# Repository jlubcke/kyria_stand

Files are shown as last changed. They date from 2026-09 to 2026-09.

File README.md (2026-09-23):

# Kyria tenting stand

Tenting stand for a splitkb Kyria rev3 half, modelled in OpenSCAD from the
official bottom-plate DXF. Two parts in one print:

- A **collar** in the keyboard's own frame: a wall perpendicular to the bottom
  plate, following the case outline, with a small inward ledge the plate rests
  on and a sloped underside below it. It tilts with the keyboard, so the case
  fits exactly at every height of the lip.
- A **pedestal** below it with vertical walls straight down to the desk. Its
  outer face is set in 1 mm so the collar overhangs it as a design line. The
  pedestal carries the optional honeycomb cut-out.

No floor, no bottom. Prints upright with no supports.

| `pattern = "none"` | `pattern = "hex"` | `pattern = "voronoi"` |
| :---: | :---: | :---: |
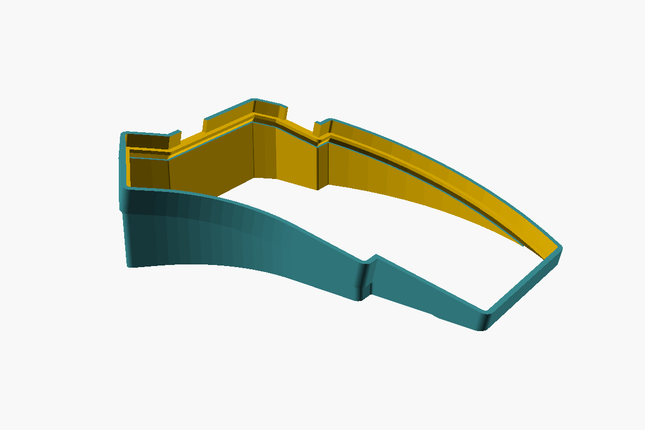
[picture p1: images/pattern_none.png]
plain walls
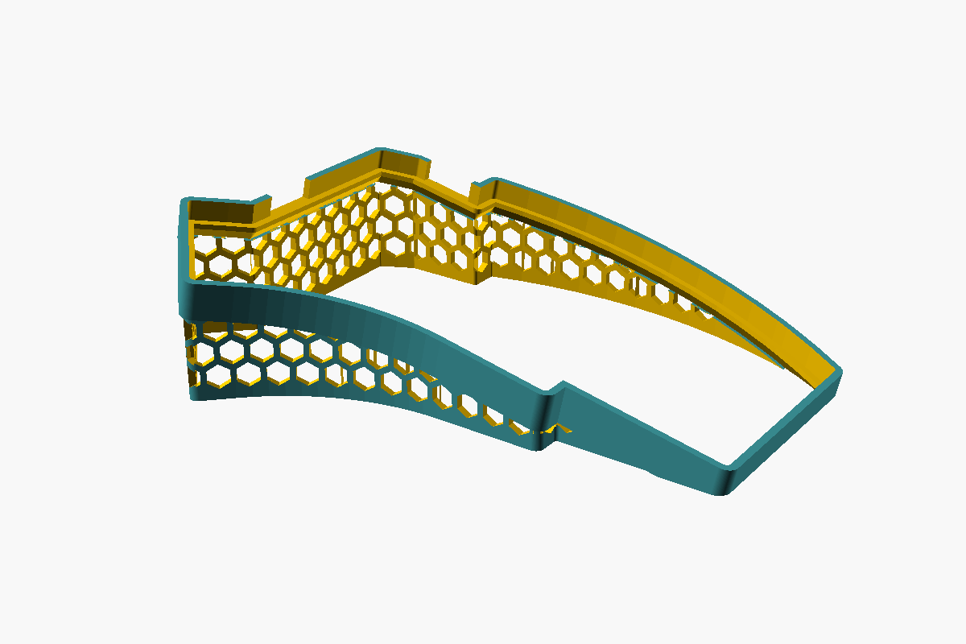
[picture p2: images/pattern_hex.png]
hex pattern
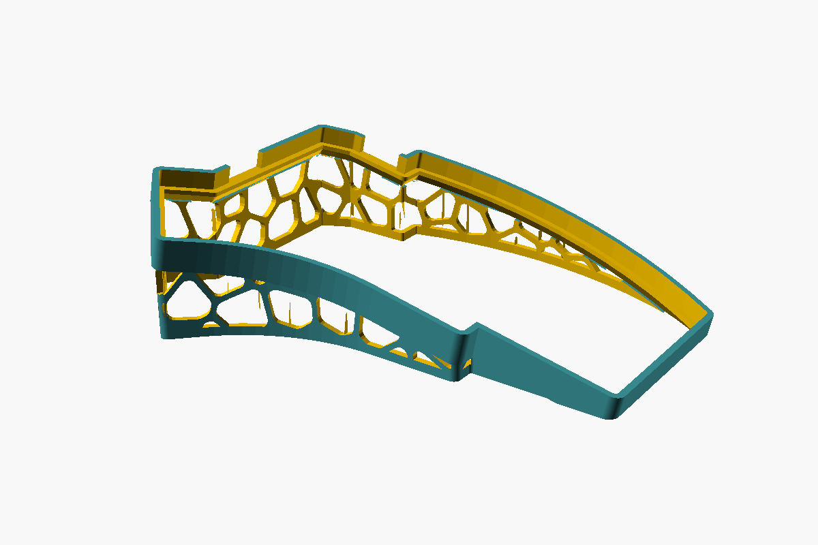
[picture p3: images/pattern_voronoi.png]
voronoi pattern
|  |  |  |

Printed:

| hex, both halves | voronoi, left half |
| :---: | :---: |
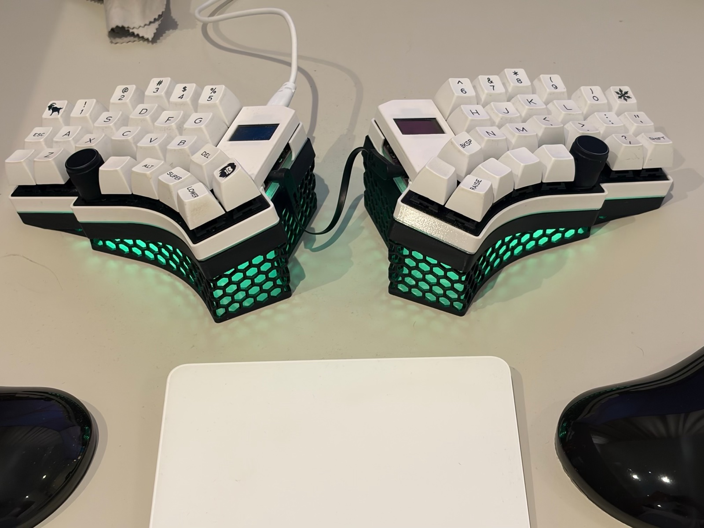
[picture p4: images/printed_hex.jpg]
printed stands with hex pattern
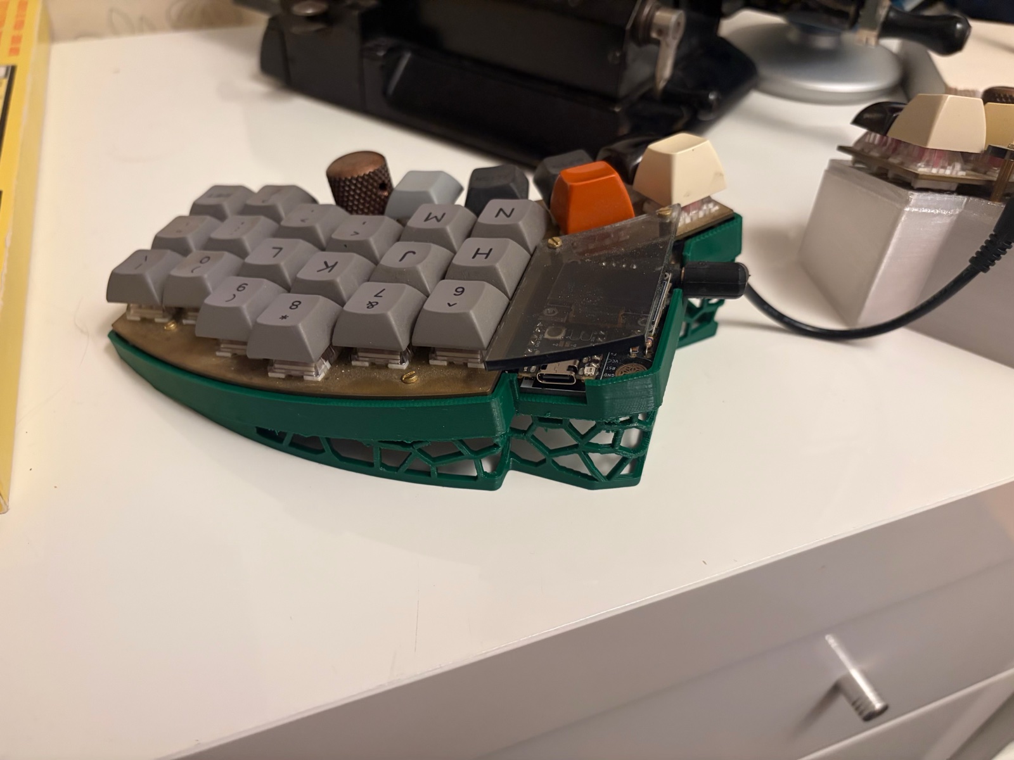
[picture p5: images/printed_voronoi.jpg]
printed stand with voronoi pattern
|  |  |

## Files

- `kyria_stand.scad` – the model, all parameters at the top
- `Kyria rev3 Bottom Plate - No Kerf.dxf` – case outline, imported directly
- `kyria_outline.scad` – coarse polyline of the outline, generated; guides the wall pattern
- `dxf2chords.py` – regenerates `kyria_outline.scad` from the DXF (only needed if the DXF changes)
- `build.sh` – renders all six STLs into `stl/`: left and right, for each pattern
- `stl/kyria_stand_<pattern>_<side>.stl` – ready to slice
- `images/` – the renders above (regenerate with `./render_images.sh`) and photos of printed stands

## Defaults

| parameter | value  | meaning |
| --- | --- | --- |
| `inner_height`  | 50 mm  | rim height at the inner (thumb/OLED) edge |
| `lip` | 6 mm | collar wall above the plate |
| `collar_extra`  | 0 mm | extra collar depth below the ledge chamfer|
| `border` | 1 mm | collar overhang beyond the pedestal wall  |
| `wall` | 2 mm | wall thickness |
| `clearance` | 0.4 mm | gap between case and pocket wall |
| `ledge_w` | 2 mm | ledge width, inward from the pocket wall  |
| `ledge_t` | 1.5 mm | ledge thickness |
| `chamfer_angle` | 57° | slope of the ledge underside, vs the plate|
| `notches_top` | `[[-50, -34]]` | USB-C notch(es) through the top-edge wall, as `[x_from, x_to]` in DXF coordinates; `[]` for none |
| `notches_side`  | `[[-6, 10]]` | TRRS notch(es) through the inner-edge wall, as `[y_from, y_to]`; `[]` for none |
| `notch_depth` | 6 mm | notch depth below the rim; 6 = down to the plate |
| `pattern` | "hex"  | wall cut-out: "hex", "voronoi" or "none"  |
| `hex_size` | 6 mm | hex: hole width, flat to flat |
| `hex_strut` | 1.6 mm | hex: material left between holes |
| `voronoi_cell`  | 14 mm  | voronoi: mean cell size |
| `voronoi_strut` | 1.8 mm | voronoi: material left between cells |
| `voronoi_jitter`| 0.8 | voronoi: 0 = regular grid, 1 = fully random |
| `voronoi_seed`  | 7 | voronoi: change for a different pattern |
| `voronoi_round` | 2.5 mm | voronoi: corner radius of each cell; 0 = sharp polygons |
| `pattern_foot`  | 3 mm | solid band along the desk |
| `pattern_top` | 1.5 mm | solid margin below the ledge chamfer |
| `corner_margin` | 0 mm | solid band either side of a sharp corner; 0 lets holes wrap around corners |

The tent angle follows from `inner_height`, `lip` and `ledge_t`: about 15°
with the defaults. The ledge underside touches the desk at the outer edge, so
the plate bottom sits about 1.5 mm above the desk there; whatever would hang
below the desk is cut off. Collar height is derived, 10.6 mm with the
defaults. Outer rim is about 7 mm tall. Footprint per half: roughly
164 × 119 mm. About 27 cm³ of plastic per half with the hex pattern.

Printed overhang of the ledge underside is `chamfer_angle` minus the tent
angle, measured from horizontal. Keep that at 40° or more.

### Cable notches

On the Kyria rev3 the controller sits in the switch-free strip along the inner
edge (x = -63…-30 in the DXF). Its USB-C port points at the top edge, centred
about 20 mm in from the inner corner; the TRRS jack points sideways out of the
inner edge, level with the bottom key row. Both positions were measured off a
photo of the assembled board, so the default notches are 16 mm wide: USB-C at
x = -50…-34 through the top wall, TRRS at y = -6…10 through the inner wall,
both cut down to plate level. If your cables already clear the 6 mm lip, set
`notches_top = []` and/or `notches_side = []`.

The pattern is laid out on the "unrolled" wall (distance along the outline
versus height) and cut through each chord of the outline along that chord's
normal, so it flows continuously around the curves. The Voronoi variant seeds
a jittered grid over that plane and wraps it around the loop, so it has no
seam either; seeds stay inside their own grid cell, which keeps cell sizes
even and rules out hairline struts. Each cell's corners are rounded by
`voronoi_round`, which turns the polygons into pebbles and the strut junctions
into smooth fillets. The holes run up to the
collar, which clips the top row; a cell is kept whenever at least
`min_hole_h` of it shows between the foot band and the collar. Neighbouring chords' cutters meet at the
corner's bisector plane, so holes fold around corners without gaps; set
`corner_margin` to a few mm if you'd rather keep the corners solid. The desk
band stays solid.

Keep `ledge_w` at 3 mm or less: the case screw nearest the edge (top inner
corner) is 5.3 mm in, and its head must clear the ledge. If your bottom plate
has rubber feet near the edge, check those too.

`side = "right"` is the DXF as drawn (inner edge on -X, seen from above);
`side = "left"` mirrors it. If the halves come out swapped, just swap the files.

## Rebuild

```bash
./build.sh
```

writes `stl/kyria_stand_{plain,hex,voronoi}_{left,right}.stl` as binary STL.
For a single variant with other parameters, call OpenSCAD directly:

```bash
openscad --enable=roof --backend=Manifold --export-format=binstl -o test.stl -D 'side="right"' -D 'pattern="hex"' -D 'hex_size=8' kyria_stand.scad
```

Needs OpenSCAD on the PATH (`brew install --cask openscad@snapshot`) and the
experimental `roof()` feature, which `build.sh` enables with `--enable=roof`.
In the GUI, turn on "roof" under Preferences > Features, and pick Manifold as
the backend under Preferences > Advanced > 3D Rendering; the preview (F5) then
takes a few seconds because the wall pattern is pre-rendered to a mesh.

## Printing

Print upright, as modelled. The collar leans with the tent angle, the ledge
underside slopes at 42–72° from horizontal, and the collar overhangs the
pedestal by 1 mm. All of that prints without supports.

## How it was made

Designed in a conversation with Claude Code, starting from a friend's printed
stand and the official Kyria bottom-plate DXF, and iterated against test
prints. The main steps:

1. **Outline from the DXF.** OpenSCAD's `import()` reads the plate outline
   directly. A grow-then-shrink `offset()` fills the five M2 screw holes so
   the pocket has a clean floor plane.
2. **Tray, then shell, then ledge.** The first version was a solid wedge with a
   pocket; then an open shell with a sloped floor; then just walls with a
   small inward ledge. The ledge underside is a chamfer made with the
   experimental `roof()` operator, which builds a 45° "hip roof" over a 2D
   shape. Scaling it in Z sets the chamfer angle, so the ledge prints upright
   without supports.
3. **Fixing the fit.** The first print was 7 mm too long along the tent
   direction: a plate tilted by 15° spans less when seen from above, but the
   pocket had been cut with vertical walls at full size. The fix was to build
   the collar in the keyboard's own frame, plate horizontal and walls
   perpendicular to it, and rotate the whole collar by the tent angle. The
   tent angle itself is solved from the target inner height, the lip, and the
   requirement that the ledge underside touches the desk at the outer edge.
4. **Collar and pedestal.** Leaning walls all the way down looked odd, so the
   tilted collar sits on a vertical-walled pedestal, set in 1 mm so the collar
   overhangs it as a visible line. The pedestal footprint is the collar's
   bottom outline projected onto the desk.
5. **Wall patterns.** The pedestal wall is "unrolled" into a flat plane
   (distance along the outline by height). A hex lattice, or a Voronoi
   diagram of a jittered seed grid, is drawn in that plane and cut through the
   wall one outline chord at a time, each chord along its own normal.
   Neighbouring cutters meet at the corner bisector plane, so holes fold
   around corners without seams. A small Python script turns the DXF arcs
   into the chord polyline; everything else is plain OpenSCAD.

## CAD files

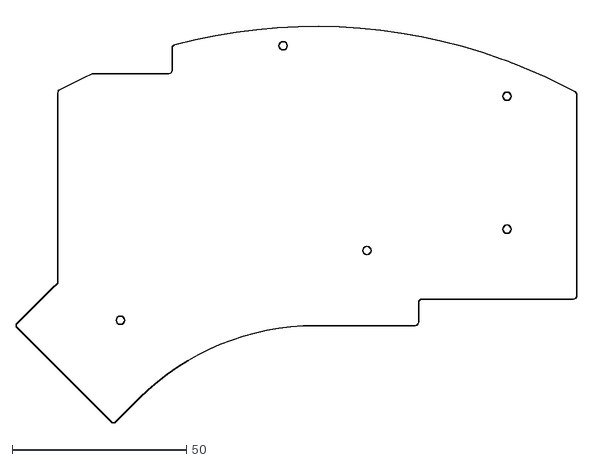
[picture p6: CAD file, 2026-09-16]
Kyria rev3 Bottom Plate - No Kerf.dxf
160.8 x 116.6

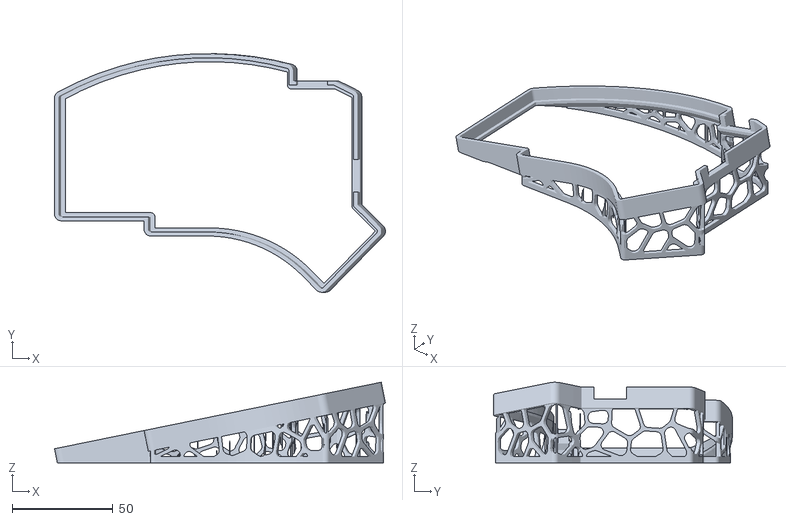
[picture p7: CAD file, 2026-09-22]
stl/kyria_stand_voronoi_left.stl
164.4 x 118.5 x 40.0

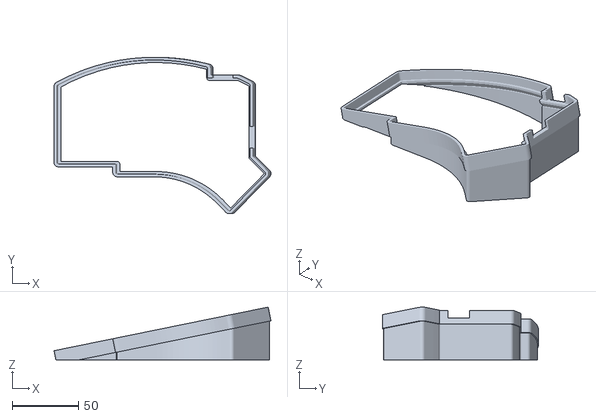
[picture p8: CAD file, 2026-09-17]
stl/kyria_stand_plain_left.stl
164.4 x 118.5 x 40.0

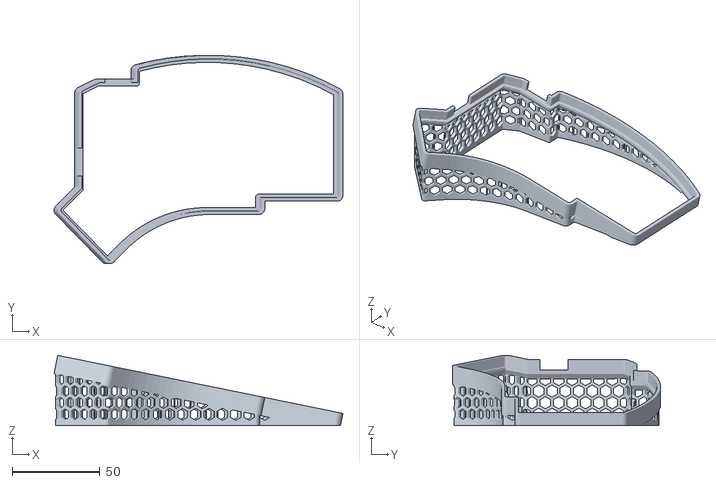
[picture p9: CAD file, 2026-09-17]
stl/kyria_stand_hex_right.stl
164.4 x 118.5 x 40.0

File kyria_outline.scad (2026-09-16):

// Generated by dxf2chords.py from Kyria rev3 Bottom Plate - No Kerf.dxf -- do not edit.
// Counter-clockwise closed loop; arcs split into chords <= 10 mm.
outline_chords = [
    [85.3611, 41.4629],
    [76.7562, 45.7581],
    [67.9046, 49.5187],
    [64.3850, 50.8402],
    [55.3260, 53.8107],
    [46.1034, 56.2263],
    [36.7514, 58.0780],
    [27.3042, 59.3591],
    [17.7967, 60.0648],
    [8.2639, 60.1925],
    [-1.2591, 59.7418],
    [-10.7372, 58.7143],
    [-20.1355, 57.1138],
    [-29.4195, 54.9462],
    [-30.1627, 53.9797],
    [-30.1627, 47.6600],
    [-31.1627, 46.6600],
    [-52.7000, 46.6600],
    [-53.1076, 46.5732],
    [-57.7804, 44.3949],
    [-62.3793, 42.0644],
    [-62.9127, 41.1799],
    [-62.9127, -12.9623],
    [-63.2472, -13.7086],
    [-67.8803, -18.0841],
    [-74.6155, -24.8193],
    [-74.6155, -26.2335],
    [-47.6748, -53.1743],
    [-46.2605, -53.1743],
    [-39.5253, -46.4391],
    [-32.5084, -40.2855],
    [-24.7484, -35.1003],
    [-16.3779, -30.9725],
    [-7.5402, -27.9725],
    [1.6134, -26.1517],
    [10.9264, -25.5413],
    [39.5014, -25.5413],
    [40.5014, -24.5413],
    [40.5014, -18.9715],
    [41.5014, -17.9715],
    [84.8873, -17.9715],
    [85.8873, -16.9715],
    [85.8873, 40.5823],
];

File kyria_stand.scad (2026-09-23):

// Tenting stand for a splitkb Kyria rev3 half.
//
// Two parts, one print:
//  * A collar in the keyboard's own frame: a wall perpendicular to the bottom
//    plate, following the case outline, with a small inward ledge the plate
//    rests on and a sloped underside below the ledge. The collar is tilted
//    with the keyboard.
//  * A pedestal below it with vertical walls, going straight down to the desk.
//    Its outer face is set in by `border`, so the collar overhangs it slightly
//    all around, as a design line. The pedestal carries the optional hex
//    pattern.
// No floor, no bottom. Prints upright without support.
//
// Needs the experimental roof() feature:
//   openscad --enable=roof -o kyria_stand_right.stl -D 'side="right"' kyria_stand.scad
// or just run ./build.sh. In the GUI enable "roof" under Preferences > Features.

// ---------- Parameters ----------------------------------------------------

// Which half. The DXF as drawn has the inner edge on -X; that is the right
// half seen from above. "left" mirrors the whole model.
side = "right"; // ["left", "right"]

inner_height  = 40;   // total height of the rim at the inner edge, above the desk (mm)
lip           = 6;    // collar wall above the plate's resting plane (mm)
collar_extra  = 0;    // extra collar depth below the ledge chamfer (mm); 0 = as short as possible
border        = 1;    // how far the collar overhangs the pedestal wall (mm)
wall          = 2;    // wall thickness, collar and pedestal (mm)
clearance     = 0.4;  // gap between case outline and pocket wall, per side (mm)
ledge_w       = 2;    // how far the ledge protrudes inward from the pocket wall (mm)
                      // keep <= 3: the nearest case screw is 5.3 mm from the edge
ledge_t       = 1.5;  // ledge thickness (mm)
chamfer_angle = 57;   // slope of the ledge underside, relative to the plate (deg)
                      // printed overhang is chamfer_angle - tent angle from horizontal; keep >= 40
outer_gap     = 0;    // lift of the ledge underside off the desk at the outer edge (mm)

// Cable notches in the collar, as ranges in the DXF's coordinates. The
// controller strip runs along the inner edge, x -63..-30. The USB-C port
// points at the top edge (the edge facing away from you), centred about
// x = -42; the TRRS jack points out of the inner side edge at about y = 2.
// Both ranges are 16 mm, so they take any plug and a few mm of misjudgement.
notches_top   = [[-50, -34]]; // [x_from, x_to] through the top-edge wall; [] for none
notches_side  = [[-6, 10]];   // [y_from, y_to] through the inner-edge wall; [] for none
notch_depth   = 6;    // how far below the rim the notches go (mm); lip = down to the plate

// Pedestal lightening pattern.
pattern       = "hex"; // ["none", "hex", "voronoi"]
hex_size      = 6;     // hex: hole width, flat to flat (mm)
hex_strut     = 1.6;   // hex: material left between holes (mm)
voronoi_cell  = 14;    // voronoi: mean cell size (mm)
voronoi_strut = 1.8;   // voronoi: material left between cells (mm)
voronoi_jitter = 0.8;  // voronoi: 0 = regular grid, 1 = fully random within the grid
voronoi_seed  = 7;     // voronoi: change for a different random pattern
voronoi_round = 2.5;   // voronoi: corner radius of each cell (mm); 0 = sharp polygons
pattern_foot  = 3;     // solid band along the desk (mm)
pattern_top   = 0;     // solid margin below the collar (mm); 0 = holes run up to the collar
min_hole_h    = 1.5;   // drop holes the collar would cut down to less than this height (mm)
corner_margin = 0;     // solid material either side of a sharp corner (mm); 0 = pattern wraps around corners
corner_deg    = 20;    // turn angle that counts as a sharp corner (deg)

dxf = "Kyria rev3 Bottom Plate - No Kerf.dxf";

// Coarse polyline of the same outline, generated by dxf2chords.py. Only used
// to place the wall pattern perpendicular to each chord of the wall.
include <kyria_outline.scad>

// Outline extents of the DXF (mm), used only to derive the tilt.
x_inner = -74.91;    // inner edge (OLED step + thumb cluster side)
x_outer =  85.89;    // outer edge (pinky side)

$fn = 96;

// ---------- Derived -------------------------------------------------------

chamfer_h    = ledge_w * tan(chamfer_angle);   // height of the sloped underside
collar_below = ledge_t + chamfer_h + collar_extra;   // collar depth below the plate
collar_h     = lip + collar_below;

// Tent angle: the rim reaches inner_height at the outer face of the inner
// wall, and the ledge underside touches the desk at the outer edge of the
// pocket (plus outer_gap). Whatever hangs below the desk there is cut off.
// Solves A*sin(a) + B*cos(a) = C.
x_lo     = x_inner - clearance - wall;         // outer face of the inner wall
x_hi     = x_outer + clearance;                // pocket edge on the outer side
A        = x_hi - x_lo;
B        = ledge_t + lip;
C        = inner_height - outer_gap;
tent_deg = asin(C / sqrt(A * A + B * B)) - atan2(B, A);
slope    = tan(tent_deg);

// Keyboard frame: plate plane through (0, 0, c_top), rotated tent_deg about Y.
c_top   = x_hi * sin(tent_deg) + ledge_t * cos(tent_deg) + outer_gap;
// Collar/pedestal joint plane, in world coords: z = c_joint - slope * x
c_joint = c_top - collar_below / cos(tent_deg);

echo(str("tent angle = ", tent_deg, " deg"));
echo(str("plate bottom above desk at the outer edge = ", ledge_t * cos(tent_deg) + outer_gap, " mm"));
echo(str("collar height = ", collar_h, " mm; outer rim height = ",
         (ledge_t + lip) * cos(tent_deg) + outer_gap, " mm, inner rim height = ", inner_height, " mm"));
echo(str("ledge underside slope, world: ", chamfer_angle - tent_deg, " to ",
         chamfer_angle + tent_deg, " deg from horizontal"));

BIG = 1000;

// ---------- 2D profiles ---------------------------------------------------

// Case outline with the M2 holes filled in (grow then shrink closes r=1.2 holes).
module plate_outline() {
    offset(delta = -2) offset(delta = 2) import(dxf);
}

module pocket_profile() { offset(r = clearance) plate_outline(); }
module outer_profile()  { offset(r = clearance + wall) plate_outline(); }
module inside_ledge()   { offset(r = -ledge_w) pocket_profile(); }

// ---------- Frames --------------------------------------------------------

// Keyboard frame -> world.
module frame() { translate([0, 0, c_top]) rotate([0, tent_deg, 0]) children(); }

// Where a 2D shape drawn on the collar's bottom plane lands on the desk,
// seen from above (the pedestal footprint).
module footprint() {
    translate([-collar_below * sin(tent_deg), 0]) scale([cos(tent_deg), 1]) children();
}

// Everything below the world plane z(x) = c - slope * x
module below(c) {
    multmatrix([[1, 0, 0, 0],
                [0, 1, 0, 0],
                [-slope, 0, 1, 0],
                [0, 0, 0, 1]])
        translate([-BIG / 2, -BIG / 2, c - BIG]) cube([BIG, BIG, BIG]);
}

// ---------- Collar (keyboard frame, plate plane at z = 0) -----------------

module collar_frame() {
    difference() {
        translate([0, 0, -collar_below]) linear_extrude(collar_h) outer_profile();
        // pocket above the plate
        linear_extrude(BIG) pocket_profile();
        // open middle, all the way through
        translate([0, 0, -BIG / 2]) linear_extrude(BIG) inside_ledge();
        // open below the ledge's sloped underside
        translate([0, 0, -BIG - ledge_t - chamfer_h]) linear_extrude(BIG) pocket_profile();
        // sloped underside: roof() rises at 45 deg from the pocket outline,
        // scaling z sets the chamfer angle
        translate([0, 0, -ledge_t - chamfer_h])
            scale([1, 1, chamfer_h / ledge_w]) roof() pocket_profile();
        // cable notches: USB-C through the top-edge wall, TRRS through the inner wall
        for (n = notches_top)
            translate([n[0], 30, lip - notch_depth]) cube([n[1] - n[0], BIG, BIG]);
        for (n = notches_side)
            translate([-BIG - 60, n[0], lip - notch_depth]) cube([BIG, n[1] - n[0], BIG]);
    }
}

// ---------- Pedestal (world frame, vertical walls) ------------------------

module pedestal() {
    difference() {
        intersection() {
            linear_extrude(BIG) footprint() offset(r = -border) outer_profile();
            below(c_joint);
        }
        translate([0, 0, -1]) linear_extrude(BIG) footprint() offset(r = -border) pocket_profile();
        // render() turns the pattern's huge CSG tree into one mesh first, so
        // the GUI preview (F5) works instead of aborting on tree size
        if (pattern != "none") render() wall_pattern();
    }
}

// ---------- Pedestal pattern ----------------------------------------------
//
// The pedestal wall is "unrolled" into (s, z) coordinates, s being distance
// along the footprint. A hex lattice is laid out in that plane, then for each
// chord of the footprint the strip of lattice over that chord is extruded
// through the wall along the chord's outward normal.
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

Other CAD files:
stl/kyria_stand_voronoi_right.stl
stl/kyria_stand_plain_right.stl
stl/kyria_stand_hex_left.stl

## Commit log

2026-09-16 First Post(TM)
    [Kyria rev3 Bottom Plate - No Kerf.dxf, kyria_stand.scad, kyria_stand_left.stl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]
2026-09-16 Dropped floor
    [kyria_stand.scad, kyria_stand_left.stl, kyria_stand_right.stl]
2026-09-16 Hex cutout
    [kyria_outline.scad, kyria_stand.scad, kyria_stand_left.stl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]
2026-09-16 Tweak pattern settings a bit
    [kyria_stand.scad, kyria_stand_left.stl, kyria_stand_right.stl]
2026-09-16 Added border
    [kyria_stand.scad, kyria_stand_left.stl, kyria_stand_right.stl]
2026-09-16 Put keyboard lower
    [kyria_stand.scad, kyria_stand_left.stl, kyria_stand_right.stl]
2026-09-16 Add voronoi pattern
    [kyria_stand.scad]
2026-09-16 Add texture also in corners
    [kyria_stand.scad, kyria_stand_left.stl, kyria_stand_right.stl]
2026-09-17 Render all .stl combinations
    [kyria_stand_hex_left.stl, kyria_stand_hex_right.stl, kyria_stand_plain_left.stl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]
2026-09-17 Added cable-notches
    [kyria_stand.scad, kyria_stand_hex_left.stl, kyria_stand_hex_right.stl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]
2026-09-17 Tweak voronoi params
    [kyria_stand.scad, kyria_stand_voronoi_left.stl, kyria_stand_voronoi_right.stl]
2026-09-17 Binary STL and prettier voronoi
    [kyria_stand.scad, kyria_stand_hex_left.stl, kyria_stand_hex_right.stl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]
2026-09-22 Prettier voronoi default
    [kyria_stand.scad, kyria_stand_voronoi_left.stl, kyria_stand_voronoi_right.stl]
2026-09-23 Added photos
    [kyria_stand.scad]
